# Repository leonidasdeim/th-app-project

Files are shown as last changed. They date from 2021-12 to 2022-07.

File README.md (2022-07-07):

# Home app project
Full solution for temperature &amp; humidity indoor monitoring. 
But main goal of the project is to add more and more home monitoring and automation functionality.

## Project structure and stack
- `th-api` - server written in *Java/SpringBoot* and *PostreSQL, Docker*.
- `th-web` - client written in *JavaScript* with *React*.
- `th-board` - PCB schematics and board, *KiCad* project.
- `th-esp` - sensor sources written with *Arduino* libraries.
- `docs` - other files

## Client preview

~~Project is published, you can check it here:
https://deimantas.tech/th/~~

Screenshot/preview of one sensor measurements:

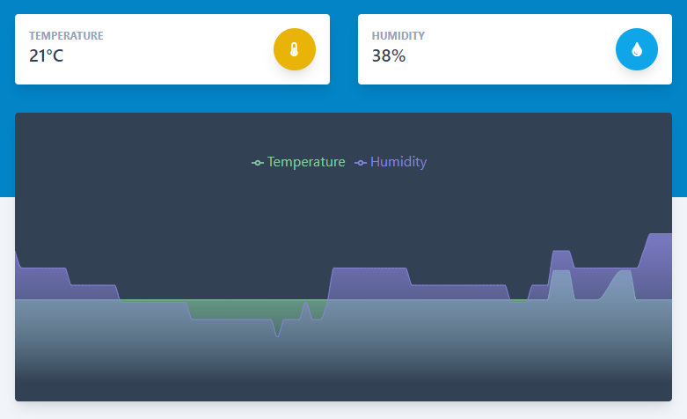
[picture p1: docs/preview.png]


## Sensor

Temperature and humidity sensor board is based on `ESP8266` microcontroller in the `ESP-12F` (or `ESP-12E`) module.
For measurements `DHT11` sensor is used

PCB Render and assembled vew:

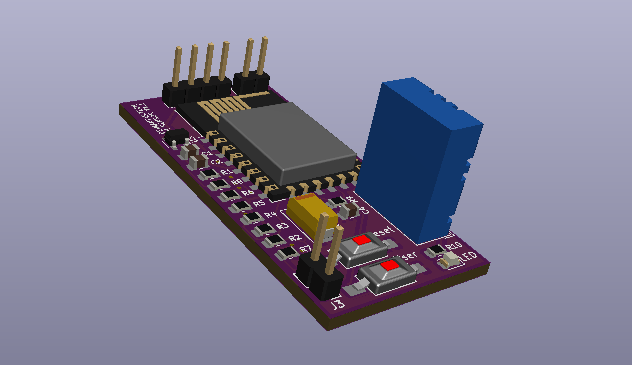
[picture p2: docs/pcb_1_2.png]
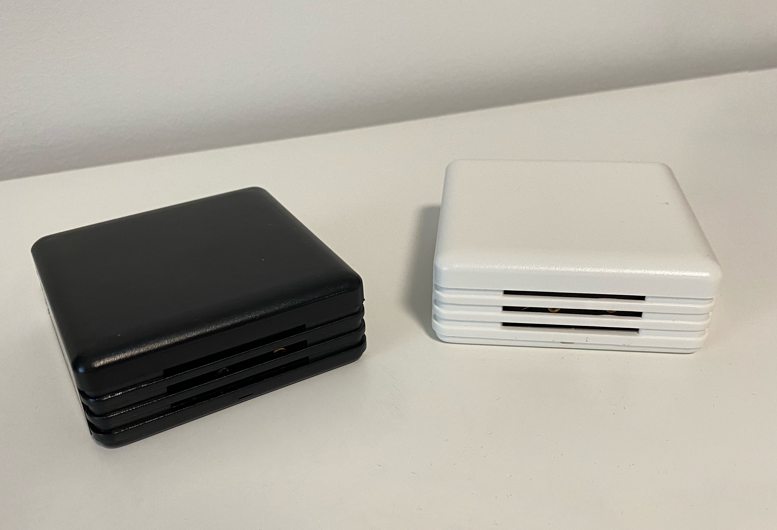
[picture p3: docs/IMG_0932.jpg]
 

## Workflow

After sensor has been turned on for the first time, it will create WiFi AP. Connect to it using your phone to configure it. You will need to enter your home WiFi info and an email of your `deimantas.tech/th` account, so sensor will register itself to your account. If something goes wrong you can always reset your sensor by pressing `reset button` while holding `user button`. After successfull configuration sensor should appear in Settings tab of the client app.

## Running locally

### Server side

To start API and database the simplest way would be to run it in docker container. Run this command in *th-app-project/th-api* folder:

`docker-compose up`

### Client

To start client application run these regular React commands in *th-app-project/th-web* folder:

`npm install`

`npm start`

> Don't forget to change API url to your own server address :)

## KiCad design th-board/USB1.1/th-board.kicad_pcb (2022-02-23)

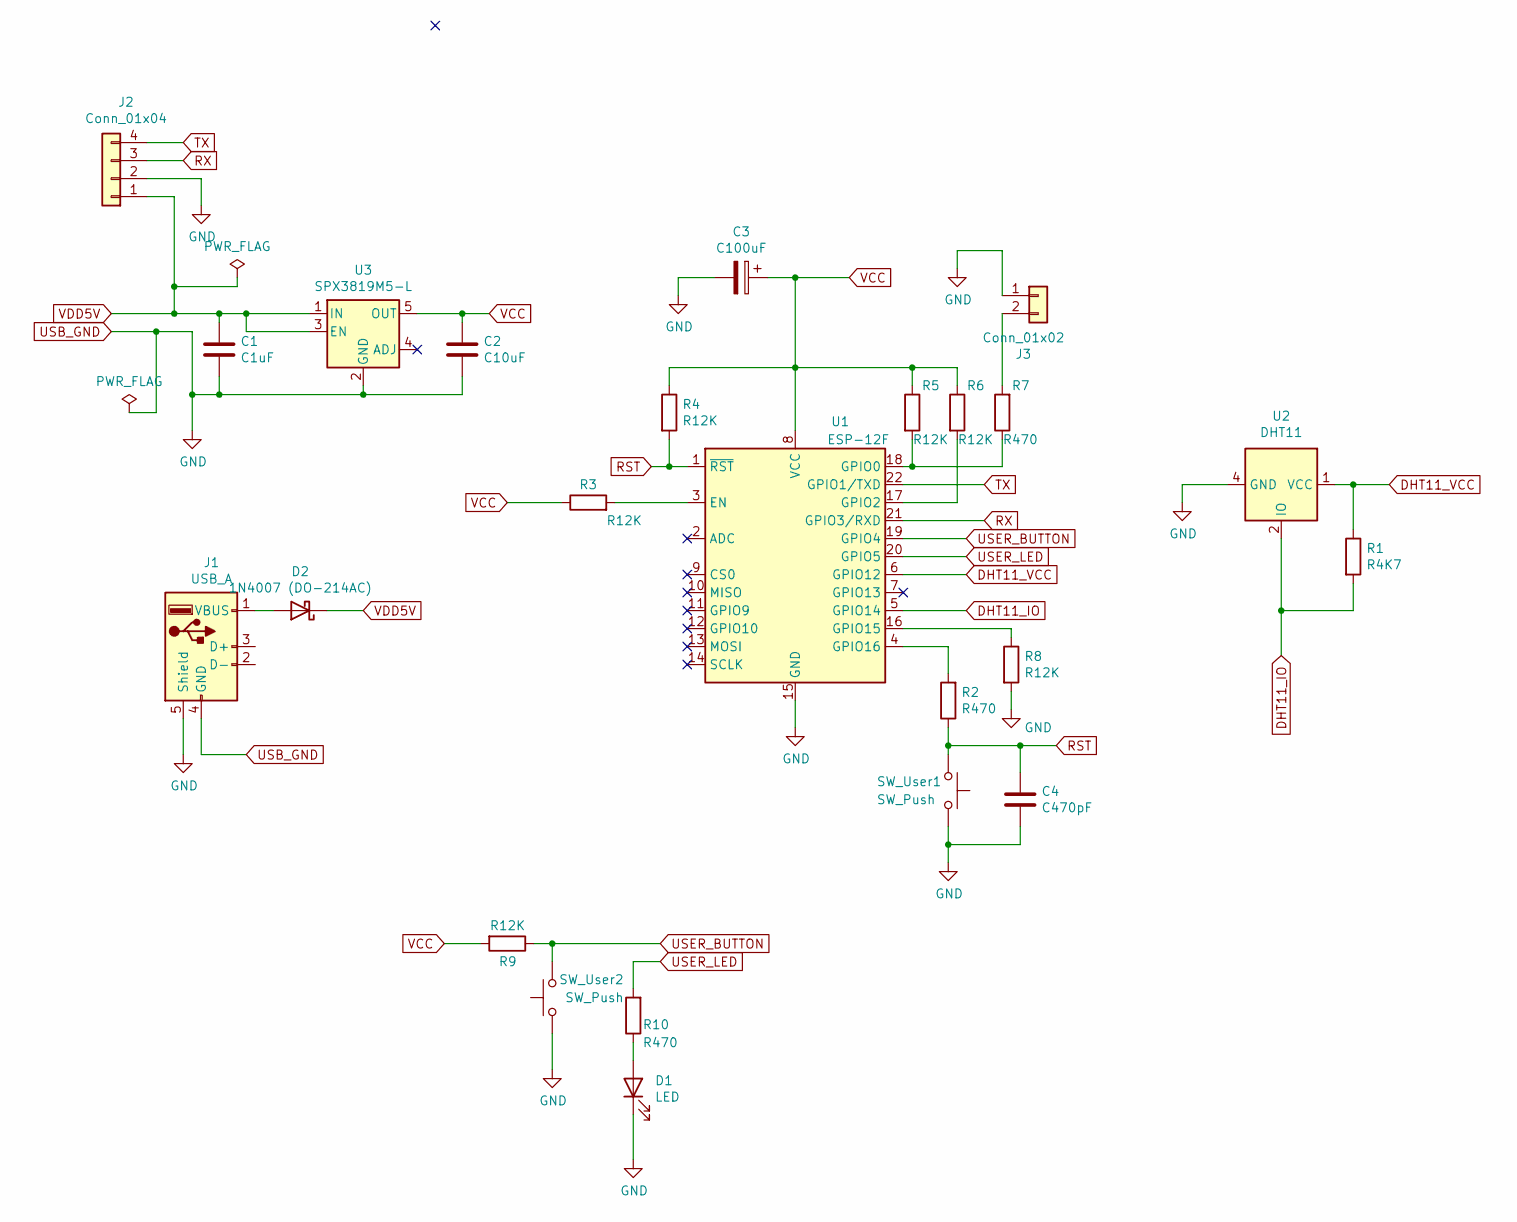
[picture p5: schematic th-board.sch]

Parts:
C1: C1uF; C_0805_2012Metric
C2: C10uF; C_0805_2012Metric
C3: C100uF; CP_EIA-6032-28_Kemet-C
C4: C470pF; C_0805_2012Metric
D1: LED; LED_0805_2012Metric
D2: 1N4007 (DO-214AC); D_SMA
J1: USB_A; USB_A_Molex_67643_Horizontal
J2: Conn_01x04; PinHeader_1x04_P2.54mm_Vertical
J3: Conn_01x02; PinHeader_1x02_P2.54mm_Vertical
R1: R4K7; R_0805_2012Metric
R2, R7, R10: R470; R_0805_2012Metric
R3, R4, R5, R6, R8, R9: R12K; R_0805_2012Metric
SW_User1, SW_User2: SW_Push; SW_SPST_FSMSM
U1: ESP-12F; ESP-12E
U2: DHT11; Aosong_DHT11_5.5x12.0_P2.54mm
U3: SPX3819M5-L; SOT-23-5

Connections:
DHT11_IO: R1.2, U1.5 (GPIO14), U2.2 (IO)
DHT11_VCC: R1.1, U1.6 (GPIO12), U2.1 (VCC)
unnamed: D1.2 (A), R10.1
unnamed: D2.2 (A), J1.1 (VBUS)
unnamed: J3.2, R7.2
unnamed: R2.2, U1.4 (GPIO16)
unnamed: R3.2, U1.3 (EN)
unnamed: R5.2, R7.1, U1.18 (GPIO0)
unnamed: R6.2, U1.17 (GPIO2)
unnamed: R8.1, U1.16 (GPIO15)
RST: C4.1, R2.1, R4.2, SW_User1.1, U1.1 (~RST); also elsewhere on the board
RX: J2.3, U1.21 (GPIO3/RXD)
TX: J2.4, U1.22 (GPIO1/TXD)
USB_GND: C1.2, C2.2, C3.2, C4.2, D1.1 (K), J1.4 (GND), J1.5 (Shield), J2.2, J3.1, R8.2, SW_User1.2, SW_User2.1, U1.15 (GND), U2.4 (GND), U3.2 (GND); also elsewhere on the board
USER_BUTTON: R9.1, SW_User2.2, U1.19 (GPIO4); also elsewhere on the board
USER_LED: R10.2, U1.20 (GPIO5)
VCC: C2.1, C3.1, R3.1, R4.1, R5.1, R6.1, R9.2, U1.8 (VCC), U3.5 (OUT)
VDD5V: C1.1, D2.1 (K), J2.1, U3.1 (IN), U3.3 (EN)

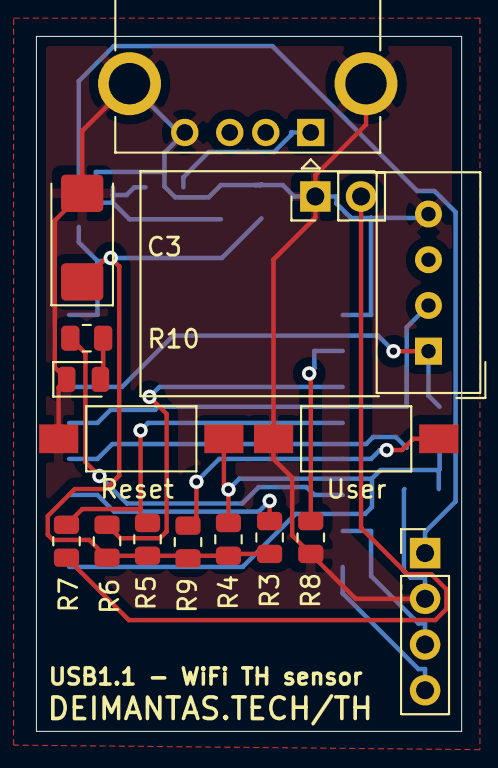
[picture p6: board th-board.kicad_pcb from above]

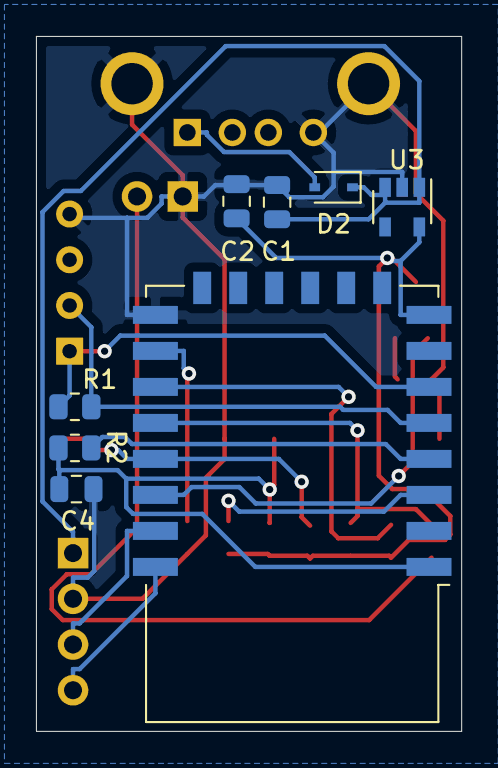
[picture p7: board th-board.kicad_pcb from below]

Board: 2 copper layers, 23.6 x 38.6 mm, 24 parts (8 on the bottom side), 18 nets.

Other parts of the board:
Reset: SW_Push; SW_SPST_FSMSM
User: SW_Push; SW_SPST_FSMSM

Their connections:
RST: Reset.1; also elsewhere on the board
USB_GND: Reset.2, User.1; also elsewhere on the board
USER_BUTTON: User.2; also elsewhere on the board

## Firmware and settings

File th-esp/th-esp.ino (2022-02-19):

#include <ESP8266WiFi.h>
#include <ESP8266HTTPClient.h>
#include <WiFiClient.h>
#include <WiFiManager.h>
#include <ESP8266WebServer.h>
#include <DNSServer.h>
#include <DHT.h>
#include <ArduinoJson.h>
#include <cstring>

#define DHT_DATA_PIN 14
#define DHT_VCC_PIN 12
#define USER_BUTTON 4
#define USER_LED 5

#define MINUTE 60e6
#define SLEEP_MIN 15
#define BAUD 115200

const char* API_DATA = "https://deimantas.tech/th-api/data";
const char* API_REGISTER = "https://deimantas.tech/th-api/sensor";

// globals
enum APP_STATE {
  CONNECT,
  CONNECT_WITH_RESET,
  MEASUREMENT,
  SENDING,
  REGISTER,
  SLEEP,
  ERR,
  NONE
};
APP_STATE state = NONE;

DHT dht; 
float temp = 0;
float humid = 0;
char macArray[15];
long sleepTime = SLEEP_MIN * MINUTE;
WiFiManagerParameter custom_email("email", "email", "", 30);
WiFiManagerParameter custom_name("sensor name", "sensor name", "", 10);

APP_STATE connectToNet();
APP_STATE sendDataApi();
APP_STATE sendRegisterApi();
APP_STATE getMeasurements();
void initialize();
bool isResetNeeded();
void goSleep();
void errorBlink();
void okBlink();

void setup(void) { 
  initialize();
}

void loop() {
  switch (state) {  
    case CONNECT:
      Serial.println("---CONNECT STATE");
      state = connectToNet(false);
      break;

    case CONNECT_WITH_RESET:
      Serial.println("---CONNECT_WITH_RESET STATE");
      state = connectToNet(true);
      break;
      
    case MEASUREMENT:
      Serial.println("---MEASUREMENT STATE");
      state = getMeasurements();
      break;  
      
    case SENDING:
      Serial.println("---SENDING STATE");
      state = sendDataApi();
      break;  

    case REGISTER:
      Serial.println("---REGISTER STATE");
      state = sendRegisterApi();
      break;  
      
    case ERR:
      Serial.println("---ERR STATE");
      Serial.println("Go to sleep for 1 min");
      errorBlink();
      sleepTime = MINUTE;
      
    case SLEEP:
      Serial.println("---SLEEP STATE");
      goSleep(sleepTime);
      break;    

    default:
      state = ERR;
      break;
  }
}

void initialize() {
  Serial.begin(BAUD);
  pinMode(USER_LED, OUTPUT);
  pinMode(USER_BUTTON, INPUT_PULLUP);
  pinMode(DHT_VCC_PIN, OUTPUT);
  digitalWrite(DHT_VCC_PIN, HIGH);
  dht.setup(DHT_DATA_PIN);  

  String tempStr = WiFi.macAddress();
  tempStr.replace(":", "");
  tempStr.toCharArray(macArray, 15);
  
  if (isResetNeeded()) {
    state = CONNECT_WITH_RESET;
  } else {
    state = CONNECT;
  }
    
  Serial.println("");
  Serial.println("-----------------------------------------------");
  Serial.println("Wakeup");
  Serial.print("Sensor ID: ");
  Serial.println(macArray);
  Serial.println("-----------------------------------------------");
}

void goSleep(long sleep) {
  digitalWrite(DHT_VCC_PIN, LOW);

  Serial.println("-----------------------------------------------");
  Serial.println("Going to sleep");
  Serial.println("-----------------------------------------------");
  ESP.deepSleep(sleep); 
}

APP_STATE getMeasurements() {
  humid = dht.getHumidity();
  temp = dht.getTemperature();
  
  Serial.print("Data from sensor received: ");
  Serial.print(temp);
  Serial.print(" ");
  Serial.println(humid);

  if(isnan(temp) || isnan(humid)) {
    return ERR;
  }

  return SENDING;
}

APP_STATE connectToNet(bool reset) {
  WiFiManager wifiManager;

  if (reset) {
    okBlink();
    wifiManager.resetSettings();
  }

  wifiManager.addParameter(&custom_email);
  wifiManager.addParameter(&custom_name);
  char buffer[100];
  sprintf(buffer, "<p>Serial number of the module is: %s</p>", macArray);
  WiFiManagerParameter custom_text(buffer);
  wifiManager.addParameter(&custom_text);
  
  wifiManager.autoConnect("HomeSensor AP");
  
  while (WiFi.status() != WL_CONNECTED) {
    Serial.println("");
    Serial.println("Connection failed");
    return ERR;
  }  

  Serial.print("Length of string ");
  Serial.println(strlen(custom_email.getValue()));
  
  if (strlen(custom_email.getValue()) > 0) return REGISTER;
  return MEASUREMENT;
}

APP_STATE sendDataApi() {
  HTTPClient http;
  WiFiClient client;
  WiFiClientSecure clientSecure;
  StaticJsonBuffer<200> JSONbuffer;   //Declaring static JSON buffer
  char JSONmessageBuffer[200];
  JsonObject& JSONencoder = JSONbuffer.createObject();
  
  JSONencoder["serial"] = macArray;
  JSONencoder["temperature"] = temp;
  JSONencoder["humidity"] = humid;
  JSONencoder.prettyPrintTo(JSONmessageBuffer, sizeof(JSONmessageBuffer));

  if (std::strncmp(API_DATA, "https", 5) == 0) {
    clientSecure.setInsecure();
    http.begin(clientSecure, API_DATA); 
  } else {
    http.begin(client, API_DATA);
  }
  
  http.addHeader("Content-Type", "application/json"); 
  
  int httpCode = http.POST(JSONmessageBuffer);   //Send the request
  
  http.end();

  Serial.println("Request:");
  Serial.println(JSONmessageBuffer);
  Serial.print("Response: ");
  Serial.println(httpCode);

  
  if (httpCode == 200) {
    Serial.println("Data sent successfully");
  } else {
    Serial.println("Failed to send");
    return ERR;
  }
  
  return SLEEP;
}

APP_STATE sendRegisterApi() {
  HTTPClient http;
  WiFiClient client;
  WiFiClientSecure clientSecure;
  StaticJsonBuffer<200> JSONbuffer;   //Declaring static JSON buffer
  char JSONmessageBuffer[200];
  JsonObject& JSONencoder = JSONbuffer.createObject();
  
  JSONencoder["serial"] = macArray;
  JSONencoder["name"] = custom_name.getValue();
  JSONencoder["email"] = custom_email.getValue();
  JSONencoder.prettyPrintTo(JSONmessageBuffer, sizeof(JSONmessageBuffer));

  if (std::strncmp(API_REGISTER, "https", 5) == 0) {
    clientSecure.setInsecure();
    http.begin(clientSecure, API_REGISTER); 
  } else {
    http.begin(client, API_REGISTER);
  }
  
  http.addHeader("Content-Type", "application/json"); 
  
  int httpCode = http.POST(JSONmessageBuffer);   //Send the request
  
  http.end();

  Serial.println("Request:");
  Serial.println(JSONmessageBuffer);
  Serial.print("Response: ");
  Serial.println(httpCode);

  
  if (httpCode == 200) {
    Serial.println("Registered successfully");
  } else {
    Serial.println("Failed to send");
    return CONNECT_WITH_RESET;
  }
  
  return MEASUREMENT;
}

bool isResetNeeded() {
  int debounceDelay = 2000;
  int value = 1;
  
   while (debounceDelay > 0) {
    value = digitalRead(USER_BUTTON);
    if (value == 1) return false;
    delay(100);
    debounceDelay -= 100;
  }

  Serial.println("Reset button activated");
  return true;
}

void errorBlink() {
  for (int i = 0; i <= 10; i++) {
    digitalWrite(USER_LED, HIGH);
    delay(500);
    digitalWrite(USER_LED, LOW);
    delay(500);
  }
}

void okBlink() {
  digitalWrite(USER_LED, HIGH);
  delay(3000);
  digitalWrite(USER_LED, LOW);
}

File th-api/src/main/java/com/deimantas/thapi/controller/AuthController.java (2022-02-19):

package com.deimantas.thapi.controller;

import com.deimantas.thapi.domain.ERole;
import com.deimantas.thapi.domain.Role;
import com.deimantas.thapi.domain.UserEntity;
import com.deimantas.thapi.payload.request.LoginRequest;
import com.deimantas.thapi.payload.request.SignupRequest;
import com.deimantas.thapi.payload.response.JwtResponse;
import com.deimantas.thapi.payload.response.MessageResponse;
import com.deimantas.thapi.repos.RoleRepository;
import com.deimantas.thapi.repos.UserRepository;
import com.deimantas.thapi.security.jwt.JwtUtils;
import com.deimantas.thapi.security.services.UserDetailsImpl;
import lombok.RequiredArgsConstructor;
import org.springframework.http.ResponseEntity;
import org.springframework.security.authentication.AuthenticationManager;
import org.springframework.security.authentication.UsernamePasswordAuthenticationToken;
import org.springframework.security.core.Authentication;
import org.springframework.security.core.context.SecurityContextHolder;
import org.springframework.security.crypto.password.PasswordEncoder;
import org.springframework.web.bind.annotation.*;

import javax.validation.Valid;
import java.util.HashSet;
import java.util.List;
import java.util.Set;
import java.util.stream.Collectors;

@RequiredArgsConstructor
@CrossOrigin
@RestController
@RequestMapping("/auth")
public class AuthController {
	private final AuthenticationManager authenticationManager;
	private final UserRepository userRepository;
	private final RoleRepository roleRepository;
	private final PasswordEncoder encoder;
	private final JwtUtils jwtUtils;

	@PostMapping("/signin")
	public ResponseEntity<?> authenticateUser(@Valid @RequestBody LoginRequest loginRequest) {

		Authentication authentication = authenticationManager.authenticate(
				new UsernamePasswordAuthenticationToken(loginRequest.getUsername(), loginRequest.getPassword()));

		SecurityContextHolder.getContext().setAuthentication(authentication);
		String jwt = jwtUtils.generateJwtToken(authentication);

		UserDetailsImpl userDetails = (UserDetailsImpl) authentication.getPrincipal();
		List<String> roles = userDetails.getAuthorities().stream()
				.map(item -> item.getAuthority())
				.collect(Collectors.toList());

		return ResponseEntity.ok(new JwtResponse(jwt,
				userDetails.getId(),
				userDetails.getUsername(),
				userDetails.getEmail(),
				roles));
	}

	@PostMapping("/signup")
	public ResponseEntity<?> registerUser(@Valid @RequestBody SignupRequest signUpRequest) {
		if (Boolean.TRUE.equals(userRepository.existsByUsername(signUpRequest.getUsername()))) {
			return ResponseEntity
					.badRequest()
					.body(new MessageResponse("Error: Username is already taken!"));
		}

		if (Boolean.TRUE.equals(userRepository.existsByEmail(signUpRequest.getEmail()))) {
			return ResponseEntity
					.badRequest()
					.body(new MessageResponse("Error: Email is already in use!"));
		}

		// Create new user's account
		UserEntity user = new UserEntity(signUpRequest.getUsername(),
				signUpRequest.getEmail(),
				encoder.encode(signUpRequest.getPassword()));

		// Set<String> strRoles = signUpRequest.getRole();
		Set<Role> roles = new HashSet<>();
		Role userRole = roleRepository.findByName(ERole.ROLE_USER)
				.orElseThrow(() -> new RuntimeException("Error: Role is not found."));
		roles.add(userRole);

		user.setRoles(roles);
		userRepository.save(user);

		return ResponseEntity.ok(new MessageResponse("User registered successfully!"));
	}
}

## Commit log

2021-11-22 Sensor registration API side
2021-11-22 Get all sensors endpoint added
2021-11-26 Kicad project initial
    [th-board.kicad_pcb, th-board.sch]
2021-12-01 First version of pcb
    [th-board.kicad_pcb, th-board.sch]
2021-12-01 Led added to pcb, v1.1
    [th-board.kicad_pcb, th-board.sch]
2021-12-03 Wifi configuration handling added, some rework regarding sensor verification
2021-12-08 WEB: dashboards initial
    [th-board.sch]
2021-12-09 PCB: new board
    [th-board.kicad_pcb]
2021-12-20 PCB: smaller board
    [th-board.kicad_pcb]
2021-12-20 WEB: fetch different sensors
2021-12-21 PCB: very small pcb :)
    [th-board.kicad_pcb, th-board.sch]
2021-12-23 WEB: fetch sensors and handle api error
2021-12-30 API: register manufactured devices feature
2021-12-30 WEB: current stats for areas
2022-01-07 API: new sensor registration
2022-01-07 PCB: some rearranges
    [th-board.kicad_pcb]
2022-01-10 ESP: register sensor automatically on setup
2022-01-10 API: automatic sensor registration
2022-01-24 API: fix bug for updating area of sensor
2022-01-24 WEB: device settings added
2022-02-19 WEB: no devices alert and device status indicator
2022-02-19 API: sonar fixes
2022-02-19 PCB: update for V1.1 support
2022-02-21 PCB: new board 'usb dongle'
    [th-board.kicad_pcb, th-board.sch]
2022-02-23 PCB: add ground fill
    [th-board.kicad_pcb]
